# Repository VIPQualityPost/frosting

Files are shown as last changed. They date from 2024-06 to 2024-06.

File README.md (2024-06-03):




Small, Nucleo-64 sized carrier for icesugar pro and colorlight i9 FPGA development boards. I designed this in order to be able to use the handful of Arduino and Morpho shields I have with these dev kits to avoid needing to use weird PMODS or breadboards. 

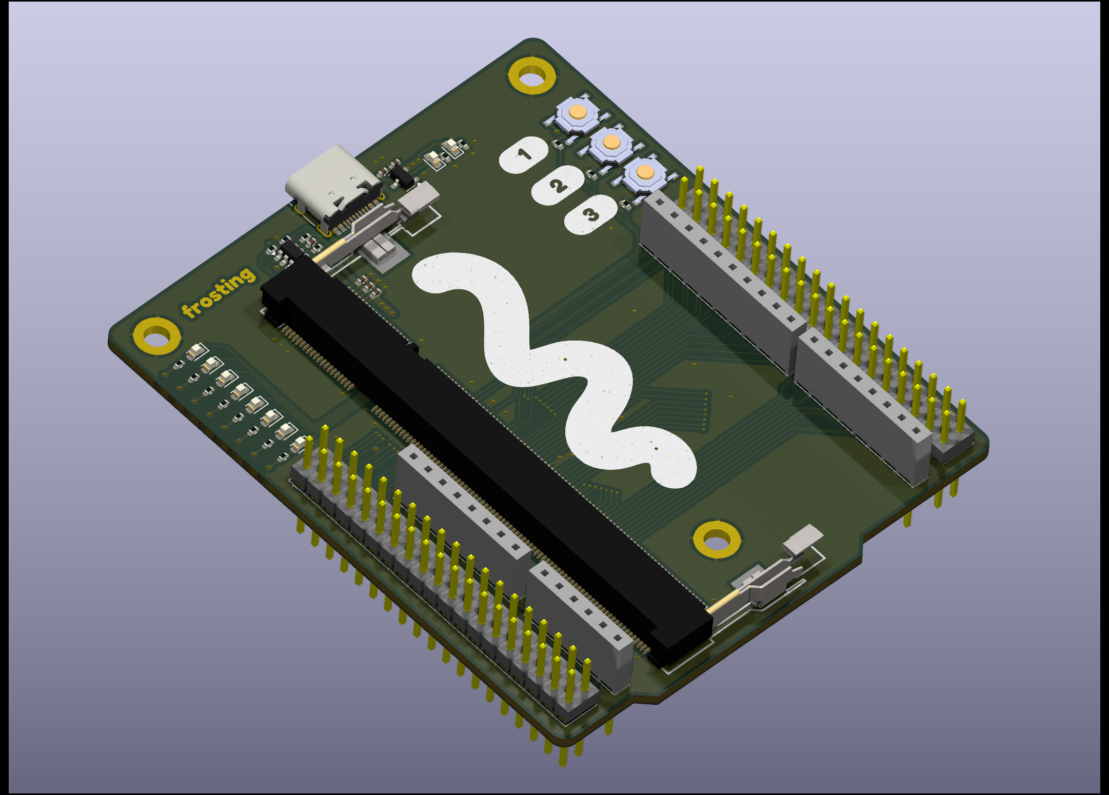
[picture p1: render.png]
Render of board


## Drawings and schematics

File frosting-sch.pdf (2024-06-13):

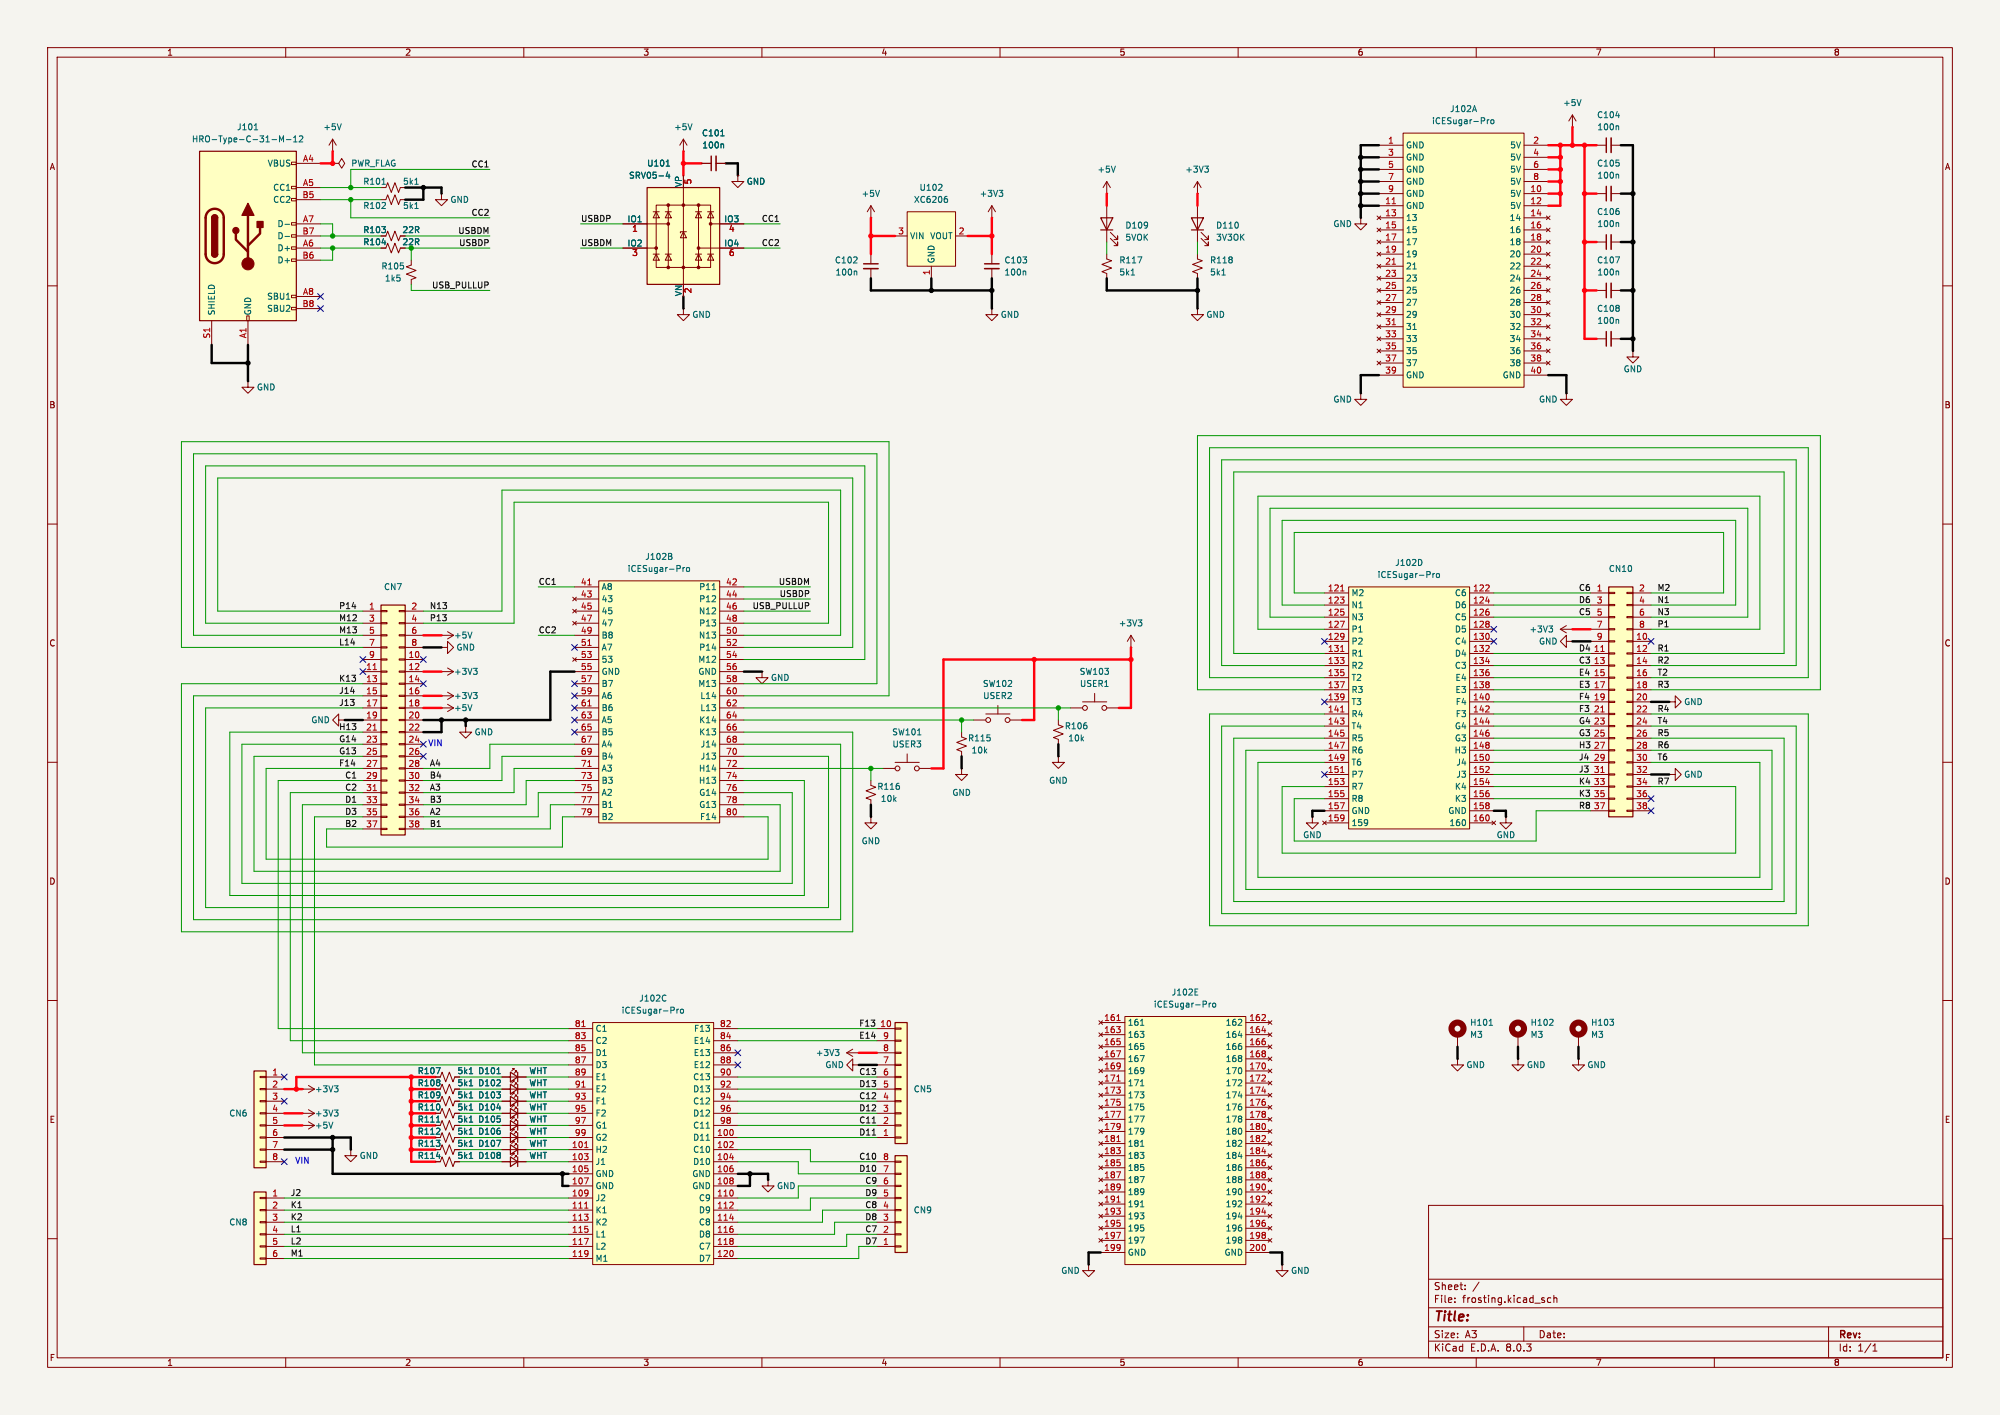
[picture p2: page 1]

Id: 1/1 Title: File: frosting.kicad_sch Sheet: /

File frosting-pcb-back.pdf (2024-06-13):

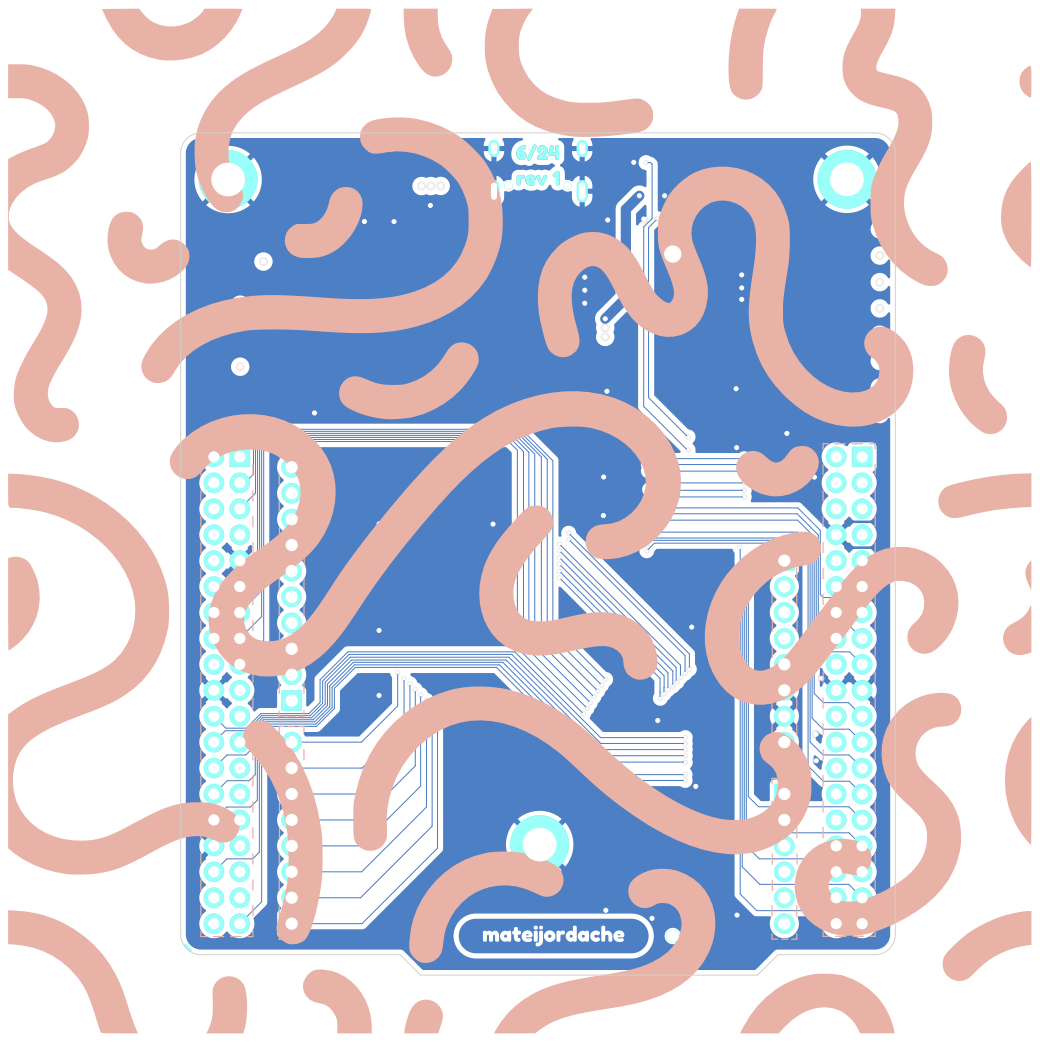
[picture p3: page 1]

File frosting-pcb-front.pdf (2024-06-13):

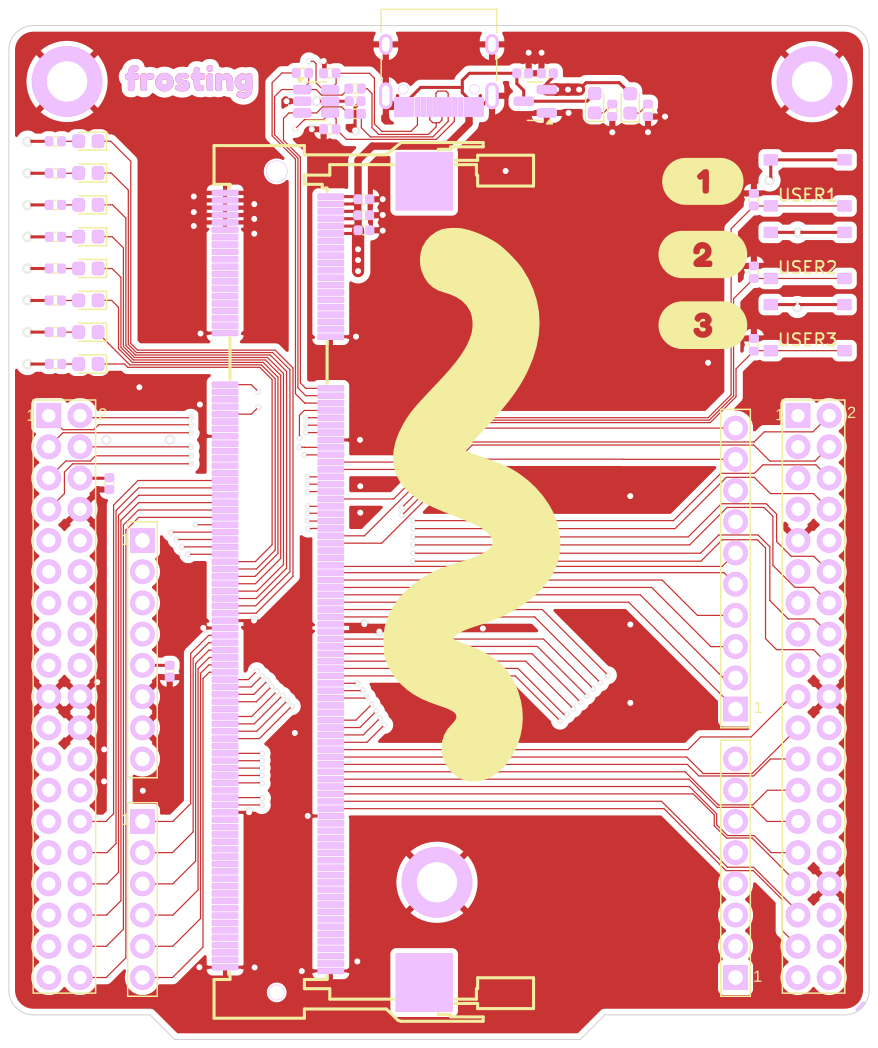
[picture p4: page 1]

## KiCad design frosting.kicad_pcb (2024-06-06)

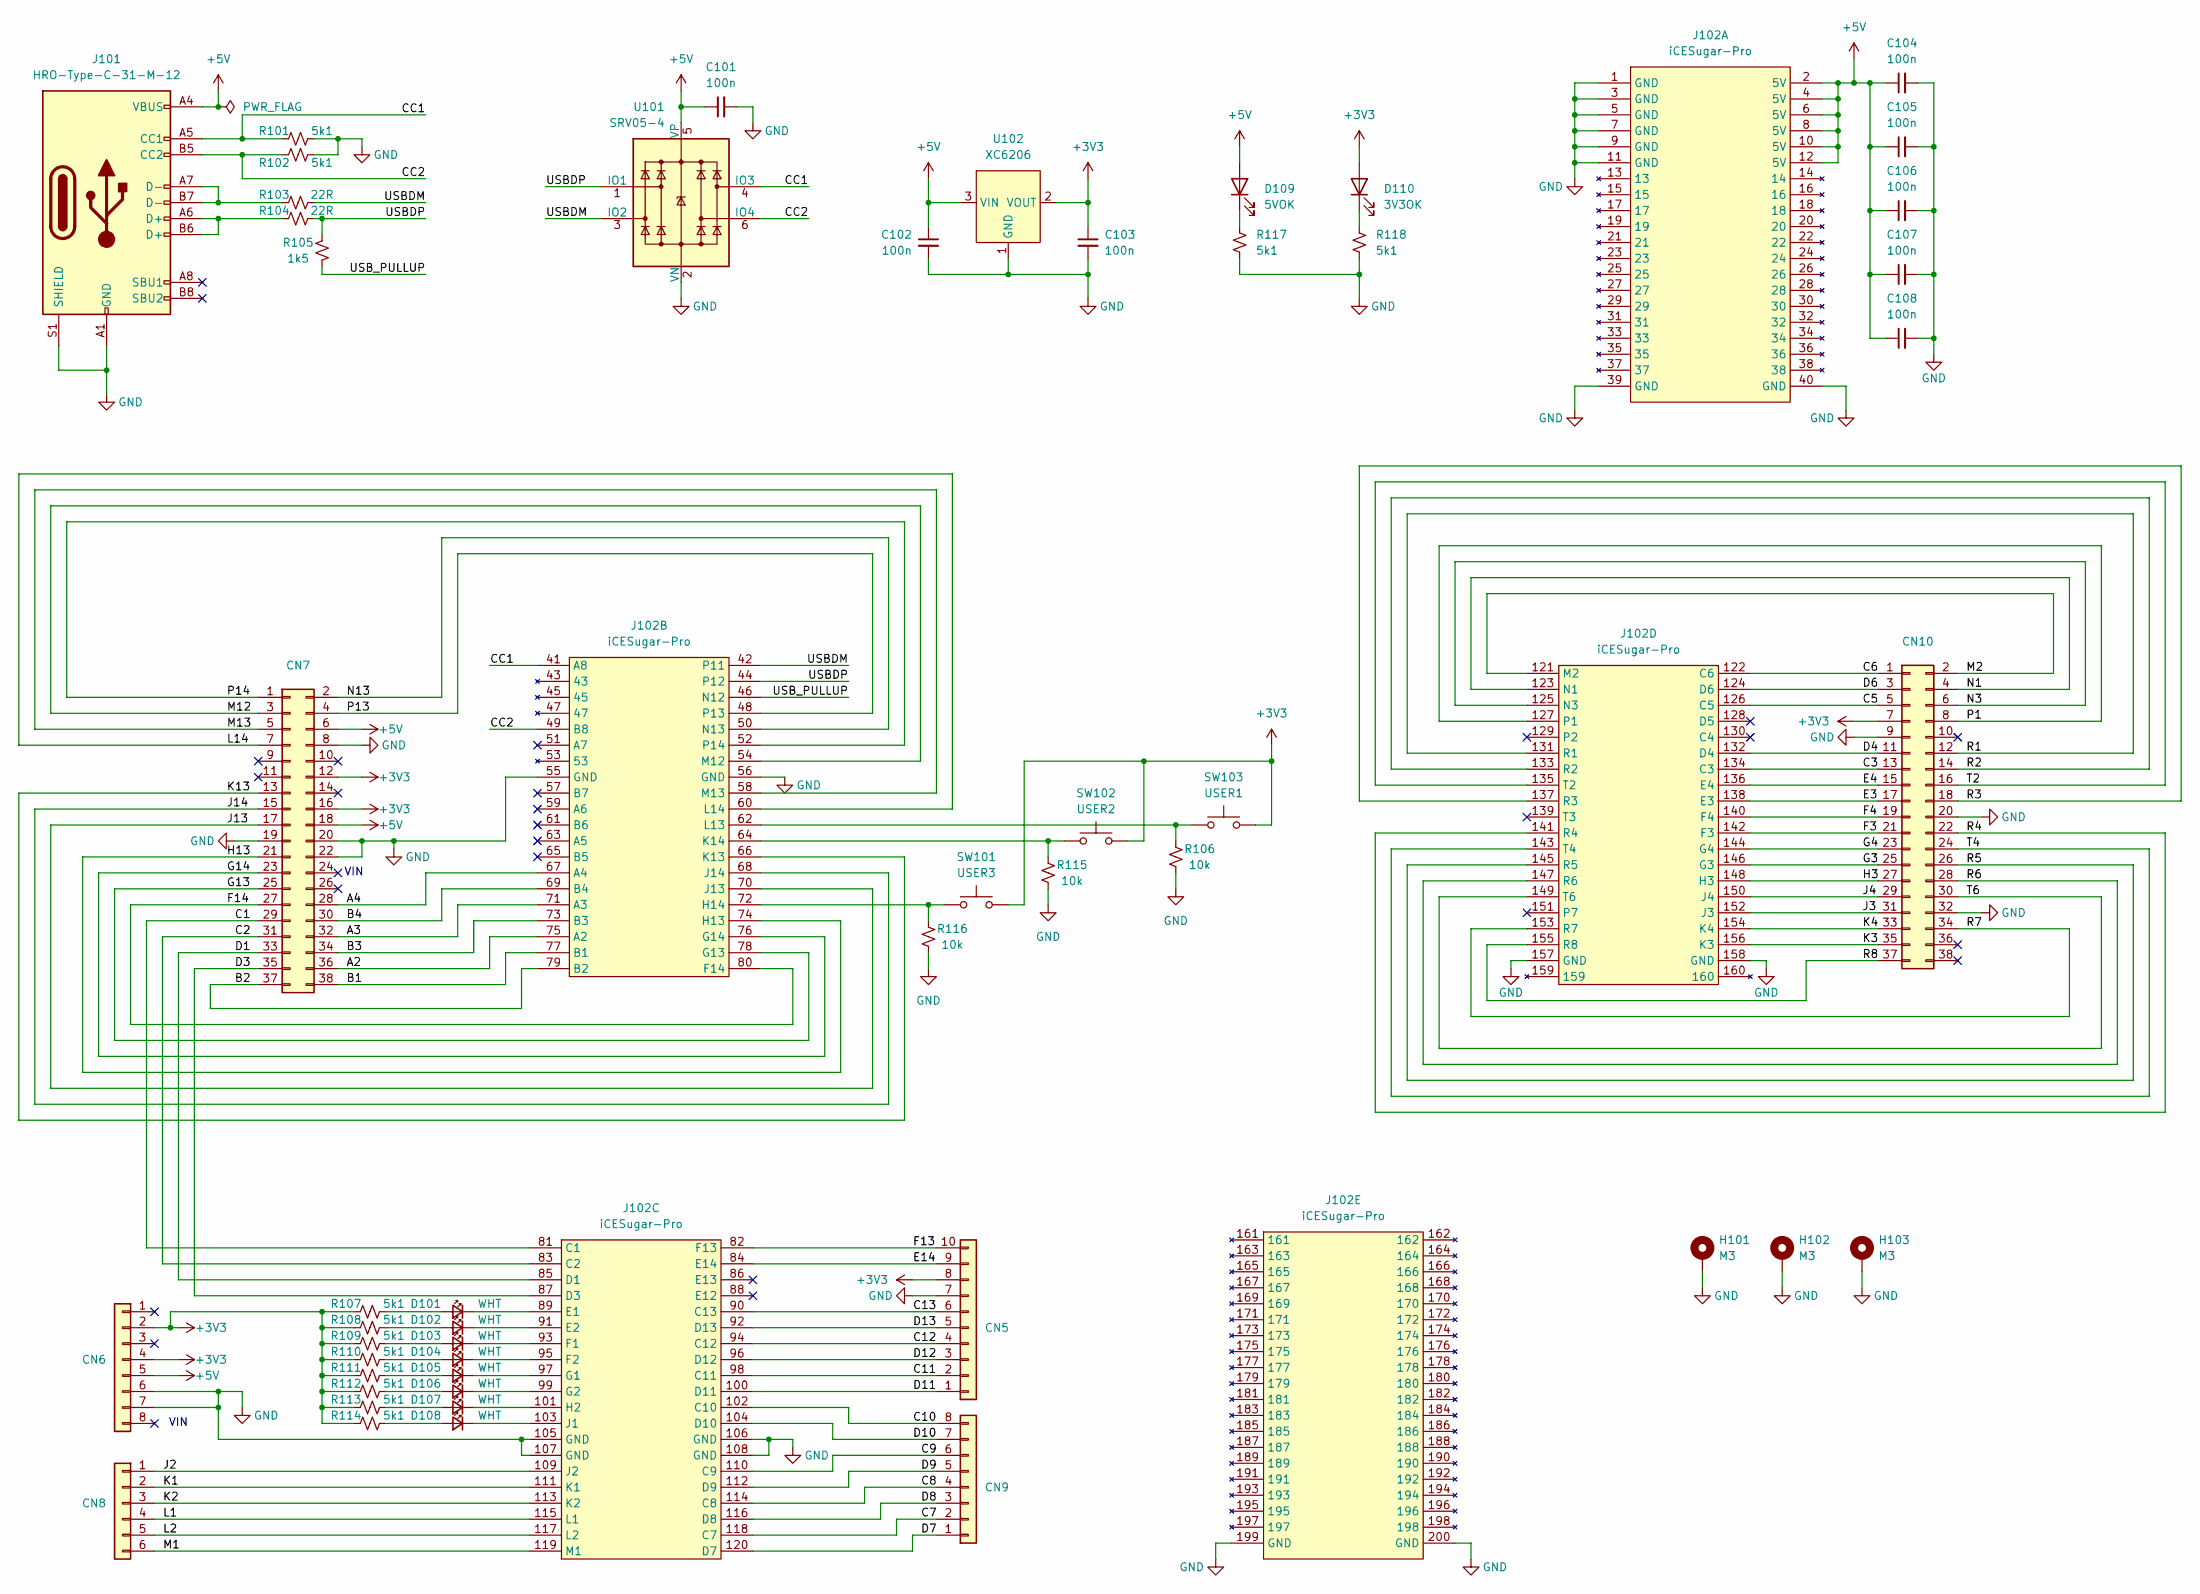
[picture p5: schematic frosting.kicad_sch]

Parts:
C101, C102, C103, C104, C105, C106, C107, C108: 100n; C_0402_1005Metric; LCSC ID C307331
CN5: CON_SAMTEC_SSW-110-03-X-S; LCSC ID C5116489
CN6, CN9: CON_SAMTEC_SSW-108-03-X-S; LCSC ID C27438
CN7, CN10: CON_SAMTEC_TSW-119-09-X-D; LCSC ID C2685155
CN8: CON_SAMTEC_SSW-106-03-X-S; LCSC ID C40877
D101, D102, D103, D104, D105, D106, D107, D108: WHT; LED_0603_1608Metric; LCSC ID C2290
D109: 5VOK; LED_0603_1608Metric; LCSC ID C2290
D110: 3V3OK; LED_0603_1608Metric; LCSC ID C2290
H101, H102, H103: M3; MountingHole_3.2mm_M3_DIN965_Pad
J101: HRO-Type-C-31-M-12; HRO-TYPE-C-31-M-12; LCSC ID C165948
J102: iCESugar-Pro; SO-DIMM-SMD_200P-P0.60_1473005-4; LCSC ID C428482
R101, R102, R107, R108, R109, R110, R111, R112, R113, R114, R117, R118: 5k1; R_0402_1005Metric; LCSC ID C25905
R103, R104: 22R; R_0402_1005Metric; LCSC ID C25092
R105: 1k5; R_0402_1005Metric; LCSC ID C25867
R106, R115, R116: 10k; R_0402_1005Metric; LCSC ID C25744
SW101: USER3; TS-1187A-B-A-B; LCSC ID C318884
SW102: USER2; TS-1187A-B-A-B; LCSC ID C318884
SW103: USER1; TS-1187A-B-A-B; LCSC ID C318884
U101: SRV05-4; SOT-23-6; LCSC ID C7420376
U102: XC6206; SOT-23; LCSC ID C5446

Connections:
+3V3: C103.1, CN5.8, CN6.2, CN6.4, CN7.12, CN7.16, CN10.7, D110.2 (A), R107.1, R108.1, R109.1, R110.1, R111.1, R112.1, R113.1, R114.1, SW101.2, SW102.2, SW103.2, U102.2 (VOUT)
+5V: C101.1, C102.1, C104.1, C105.1, C106.1, C107.1, C108.1, CN6.5, CN7.6, CN7.18, D109.2 (A), J101.A4 (VBUS), J101.A9 (VBUS), J101.B4 (VBUS), J101.B9 (VBUS), J102.2 (5V), J102.4 (5V), J102.6 (5V), J102.8 (5V), J102.10 (5V), J102.12 (5V), U101.5 (VP), U102.3 (VIN)
/A2: CN7.36, J102.75 (A2)
/A3: CN7.32, J102.71 (A3)
/A4: CN7.28, J102.67 (A4)
/B1: CN7.38, J102.77 (B1)
/B2: CN7.37, J102.79 (B2)
/B3: CN7.34, J102.73 (B3)
/B4: CN7.30, J102.69 (B4)
/C1: CN7.29, J102.81 (C1)
/C2: CN7.31, J102.83 (C2)
/C3: CN10.13, J102.134 (C3)
/C5: CN10.5, J102.126 (C5)
/C6: CN10.1, J102.122 (C6)
/C7: CN9.2, J102.118 (C7)
/C8: CN9.4, J102.114 (C8)
/C9: CN9.6, J102.110 (C9)
/C10: CN9.8, J102.102 (C10)
/C11: CN5.2, J102.98 (C11)
/C12: CN5.4, J102.94 (C12)
/C13: CN5.6, J102.90 (C13)
/CC1: J101.A5 (CC1), J102.41 (A8), R101.1, U101.4 (IO3)
/CC2: J101.B5 (CC2), J102.49 (B8), R102.2, U101.6 (IO4)
/D1: CN7.33, J102.85 (D1)
/D3: CN7.35, J102.87 (D3)
/D4: CN10.11, J102.132 (D4)
/D6: CN10.3, J102.124 (D6)
/D7: CN9.1, J102.120 (D7)
/D8: CN9.3, J102.116 (D8)
/D9: CN9.5, J102.112 (D9)
/D10: CN9.7, J102.104 (D10)
/D11: CN5.1, J102.100 (D11)
/D12: CN5.3, J102.96 (D12)
/D13: CN5.5, J102.92 (D13)
/E3: CN10.17, J102.138 (E3)
/E4: CN10.15, J102.136 (E4)
/E14: CN5.9, J102.84 (E14)
/F3: CN10.21, J102.142 (F3)
/F4: CN10.19, J102.140 (F4)
/F13: CN5.10, J102.82 (F13)
/F14: CN7.27, J102.80 (F14)
/G3: CN10.25, J102.146 (G3)
/G4: CN10.23, J102.144 (G4)
/G13: CN7.25, J102.78 (G13)
/G14: CN7.23, J102.76 (G14)
/H3: CN10.27, J102.148 (H3)
/H13: CN7.21, J102.74 (H13)
/J2: CN8.1, J102.109 (J2)
/J3: CN10.31, J102.152 (J3)
/J4: CN10.29, J102.150 (J4)
/J13: CN7.17, J102.70 (J13)
/J14: CN7.15, J102.68 (J14)
/K1: CN8.2, J102.111 (K1)
/K2: CN8.3, J102.113 (K2)
/K3: CN10.35, J102.156 (K3)
/K4: CN10.33, J102.154 (K4)
/K13: CN7.13, J102.66 (K13)
/L1: CN8.4, J102.115 (L1)
/L2: CN8.5, J102.117 (L2)
/L14: CN7.7, J102.60 (L14)
/M1: CN8.6, J102.119 (M1)
/M2: CN10.2, J102.121 (M2)
/M12: CN7.3, J102.54 (M12)
/M13: CN7.5, J102.58 (M13)
/N1: CN10.4, J102.123 (N1)
/N3: CN10.6, J102.125 (N3)
/N13: CN7.2, J102.50 (N13)
/P1: CN10.8, J102.127 (P1)
/P13: CN7.4, J102.48 (P13)
/P14: CN7.1, J102.52 (P14)
/R1: CN10.12, J102.131 (R1)
/R2: CN10.14, J102.133 (R2)
/R3: CN10.18, J102.137 (R3)
/R4: CN10.22, J102.141 (R4)
/R5: CN10.26, J102.145 (R5)
/R6: CN10.28, J102.147 (R6)
/R7: CN10.34, J102.153 (R7)
/R8: CN10.37, J102.155 (R8)
/T2: CN10.16, J102.135 (T2)
/T4: CN10.24, J102.143 (T4)
/T6: CN10.30, J102.149 (T6)
/USBDM: J102.42 (P11), R103.2, U101.3 (IO2)
/USBDP: J102.44 (P12), R104.1, R105.1, U101.1 (IO1)
/USB_PULLUP: J102.46 (N12), R105.2
GND: C101.2, C102.2, C103.2, C104.2, C105.2, C106.2, C107.2, C108.2, CN5.7, CN6.6, CN6.7, CN7.8, CN7.19, CN7.20, CN7.22, CN10.9, CN10.20, CN10.32, H101.1, H102.1, H103.1, J101.A1 (GND), J101.A12 (GND), J101.B1 (GND), J101.B12 (GND), J101.S1 (SHIELD), J102.1 (GND), J102.3 (GND), J102.5 (GND), J102.7 (GND), J102.9 (GND), J102.11 (GND), J102.39 (GND), J102.40 (GND), J102.55 (GND), J102.56 (GND), J102.105 (GND), J102.106 (GND), J102.107 (GND), J102.108 (GND), J102.157 (GND), J102.158 (GND), J102.199 (GND), J102.200 (GND), R101.2, R102.1, R106.2, R115.2, R116.2, R117.2, R118.2, U101.2 (VN), U102.1 (GND)
unnamed: D101.2 (A), R107.2
unnamed: D101.1 (K), J102.89 (E1)
unnamed: D102.2 (A), R108.2
unnamed: D102.1 (K), J102.91 (E2)
unnamed: D103.2 (A), R109.2
unnamed: D103.1 (K), J102.93 (F1)
unnamed: D104.2 (A), R110.2
unnamed: D104.1 (K), J102.95 (F2)
unnamed: D105.2 (A), R111.2
unnamed: D105.1 (K), J102.97 (G1)
unnamed: D106.2 (A), R112.2
unnamed: D106.1 (K), J102.99 (G2)
unnamed: D107.2 (A), R113.2
unnamed: D107.1 (K), J102.101 (H2)
unnamed: D108.2 (A), R114.2
unnamed: D108.1 (K), J102.103 (J1)
unnamed: D109.1 (K), R117.1
unnamed: D110.1 (K), R118.1
unnamed: J101.A6 (D+), J101.B6 (D+), R104.2
unnamed: J101.A7 (D-), J101.B7 (D-), R103.1
unnamed: J102.72 (H14), R116.1, SW101.1
unnamed: J102.64 (K14), R115.1, SW102.1
unnamed: J102.62 (L13), R106.1, SW103.1

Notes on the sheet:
VIN

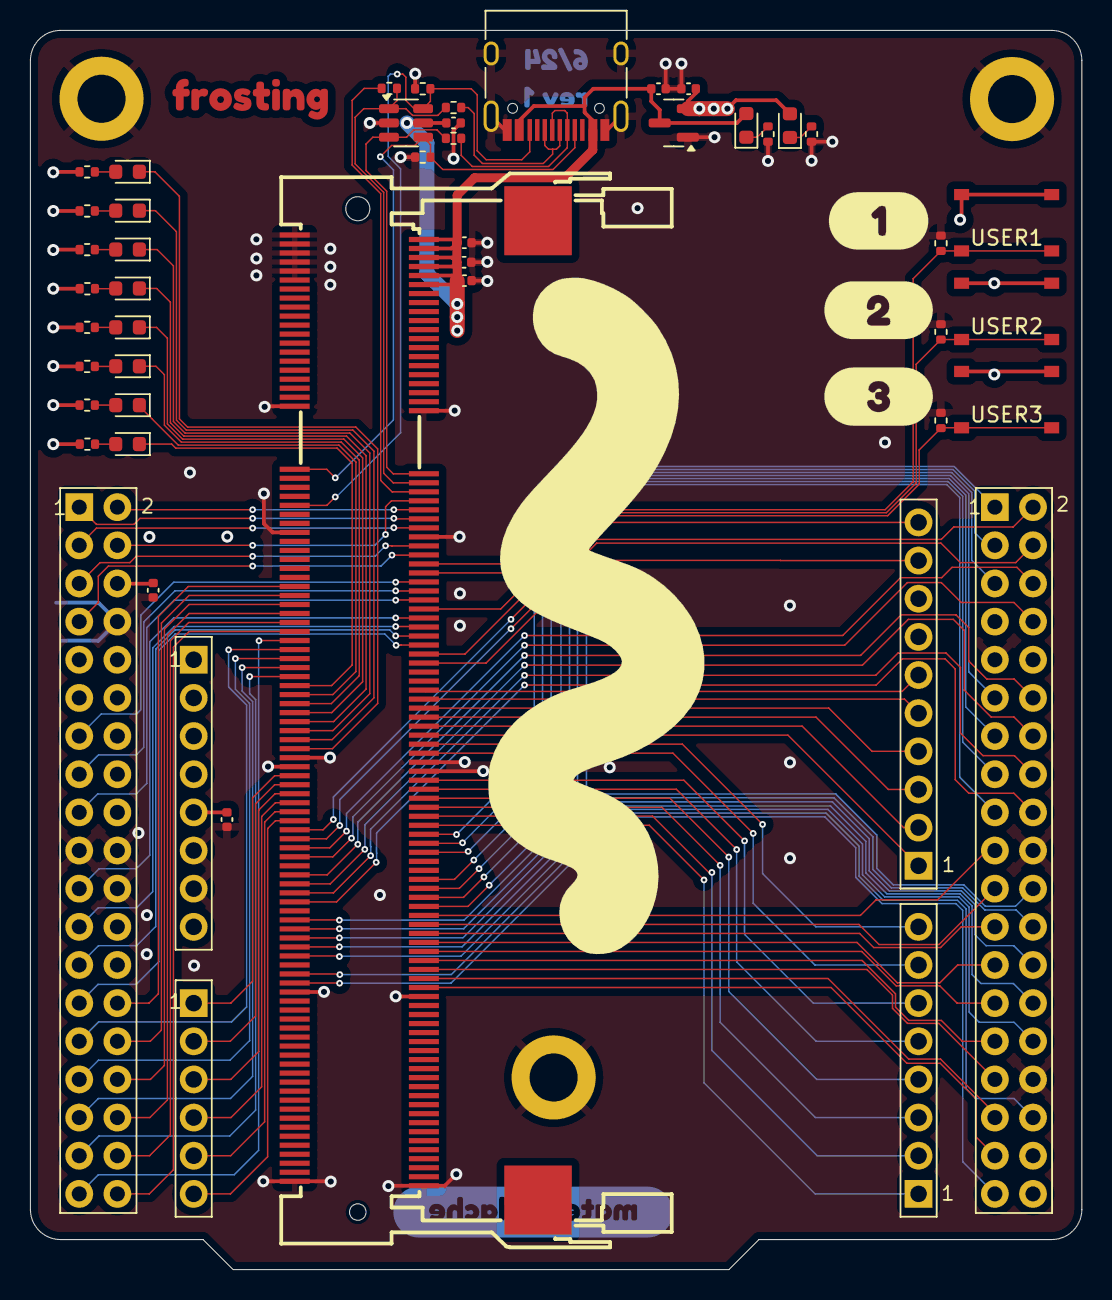
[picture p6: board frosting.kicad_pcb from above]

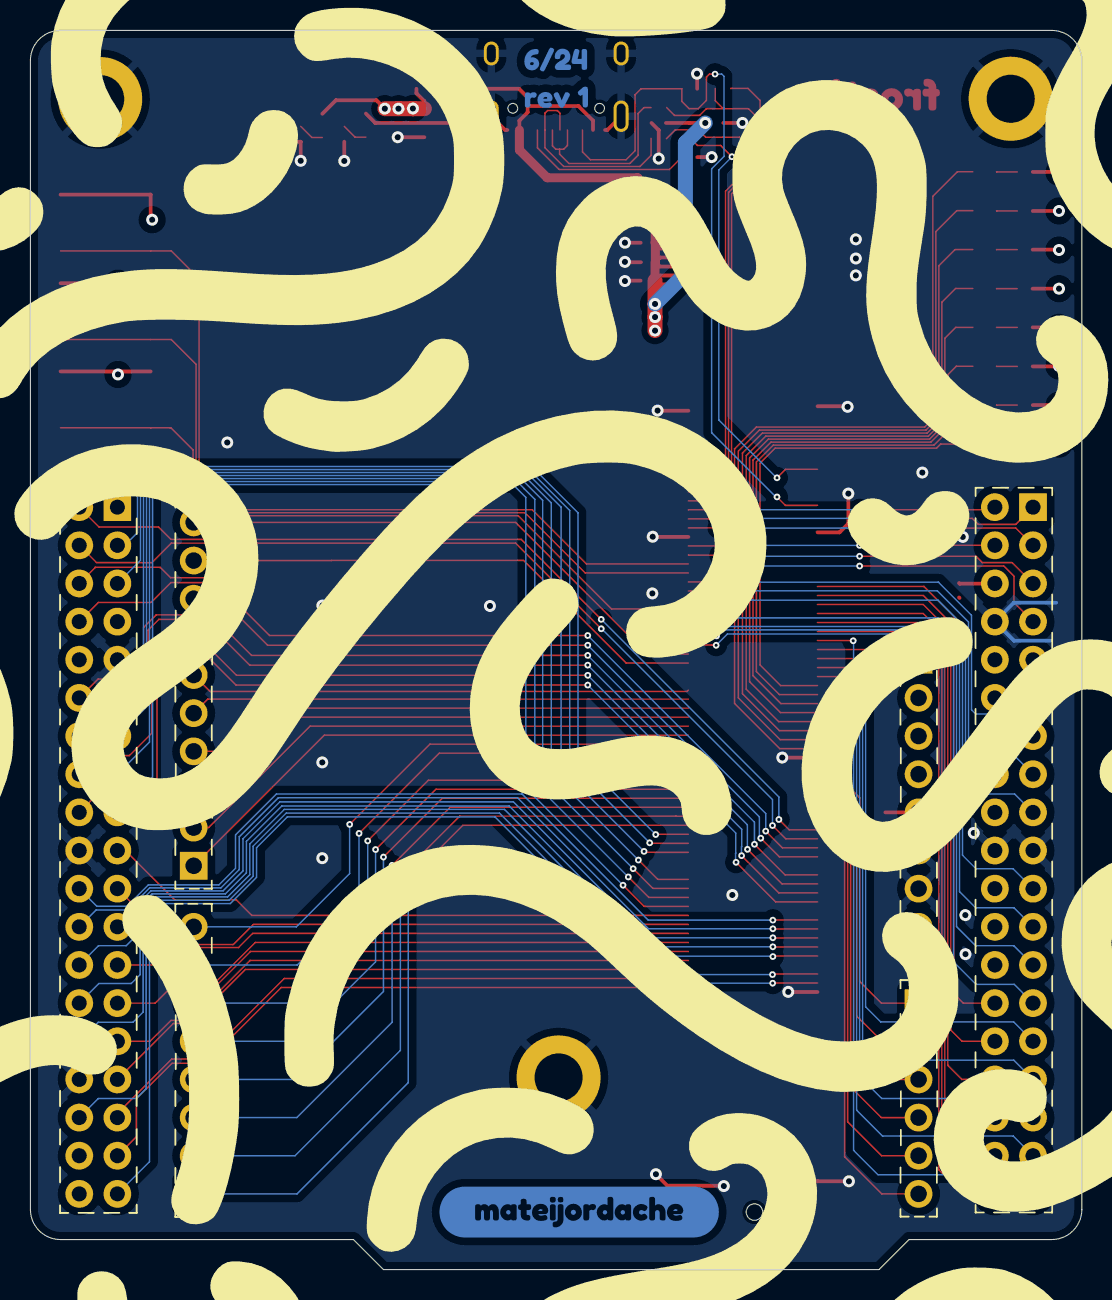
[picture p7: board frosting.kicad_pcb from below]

Board: 4 copper layers, 70.0 x 82.5 mm, 58 parts (2 on the bottom side), 108 nets.

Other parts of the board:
kibuzzard-665D4EF8: G***; kibuzzard-665D4EF8
kibuzzard-665D4EFE: G***; kibuzzard-665D4EFE
kibuzzard-665D4F04: G***; kibuzzard-665D4F04
kibuzzard-665D4F76: G***; kibuzzard-665D4F76
kibuzzard-665D4FC5: G***; kibuzzard-665D4FC5
kibuzzard-665D501B: G***; kibuzzard-665D501B

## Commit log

2024-06-04 clean erc drc
    [frosting.kicad_pcb, frosting.kicad_sch]
2024-06-04 mask silk
    [frosting.kicad_pcb]
2024-06-06 update grid origin and change 1x10P PN
    [frosting.kicad_pcb, frosting.kicad_sch]
2024-06-06 Update layer names
    [frosting.kicad_pcb]
